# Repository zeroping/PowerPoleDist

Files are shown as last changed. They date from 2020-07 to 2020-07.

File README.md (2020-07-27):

# PowerPoleDist

An Anderson PowerPole DC power distribution box.

## What is this thing?

Amateur radio hobbyists (among others) have lots of electronic gear running off of 12 VDC, and to keep the wiring a little cleaner, many of them use PowerPole connectors from Anderson Power Products. These handy little connectors can handle up to 45 amps, and have become a defacto standard.

One of the common accessories is a power breakout, basically a “power strip” for these 12 V connections. These are available from several vendors for under $100, but I wanted some slightly different features (namely, right-angle connectors), so I designed my own.

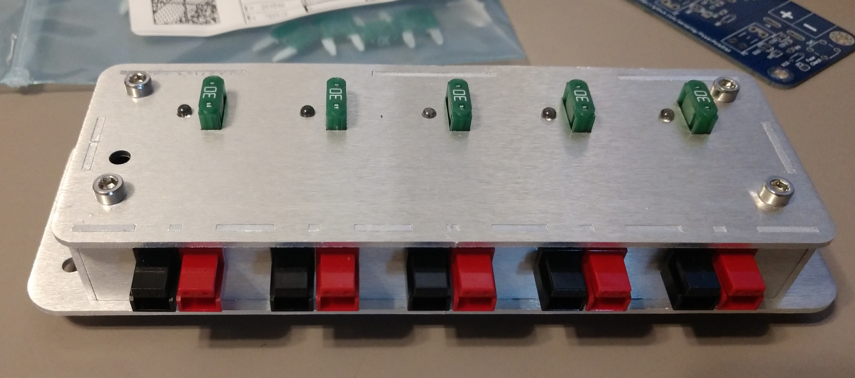
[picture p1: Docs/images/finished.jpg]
The finished design


It can handle at least 30 amps, but past that, you might want to order the PCB with 2 oz/inch copper, or solder copper wires to the PCB to lower the trace resistance.

This design is as open as I can easily make it, so if you want to change something, add something, etc, you can. The one catch is that I don't have the full 3D models for the case published (license issues), but I do have the resulting 2D shapes, so you can order your own case or make simple modifications.

The documentation should be viewable in [a pretty format on Github Pages](https://zeroping.github.io/PowerPoleDist/), or [directly in the GitHub project directory along side all the source files](https://github.com/zeroping/PowerPoleDist).

## What does it take to build one?

This design consists of:
- A custom circuit board that you can order online (design files provided)
- Electronic components that you can order from most suppliers (I used Digikey)
- A few harder-to-get components (the power connectors) available from more specialized shop (I used [Powerwerx](https://powerwerx.com/anderson-power-powerpole-sb-connectors))
- An aluminum case that you can order from a place like SendCutSend (design files provided)
- Some spacers and bolts and such that you can order from a mechanical parts supplier (I used McMaster-Carr)
 
It takes some through-hole soldering and some assembly, but the largest issue with the design is the shipping costs and one-time costs for the custom parts. The parts cost is around $30 per system, but you could easily spend three times that if you ordered just one of these, since you’re buying and shipping parts from five different vendors.

As a result, I think this design is most useful for someone building several for all their amateur radio friends, or someone who is looking for a design to modify or extend.

## Ordering Components

###  PCB files

The PCB production files are in the PCB/gerbers directory. You should be able to use the zip file as-is for most PCB manufacturers. I recommend the wonderful [PCB Shopper](https://pcbshopper.com/) to price-compare for a 2-layer, 40 x 130mm board. You might want to [check for any github issues](https://github.com/zeroping/PowerPoleDist/issues) before you order.

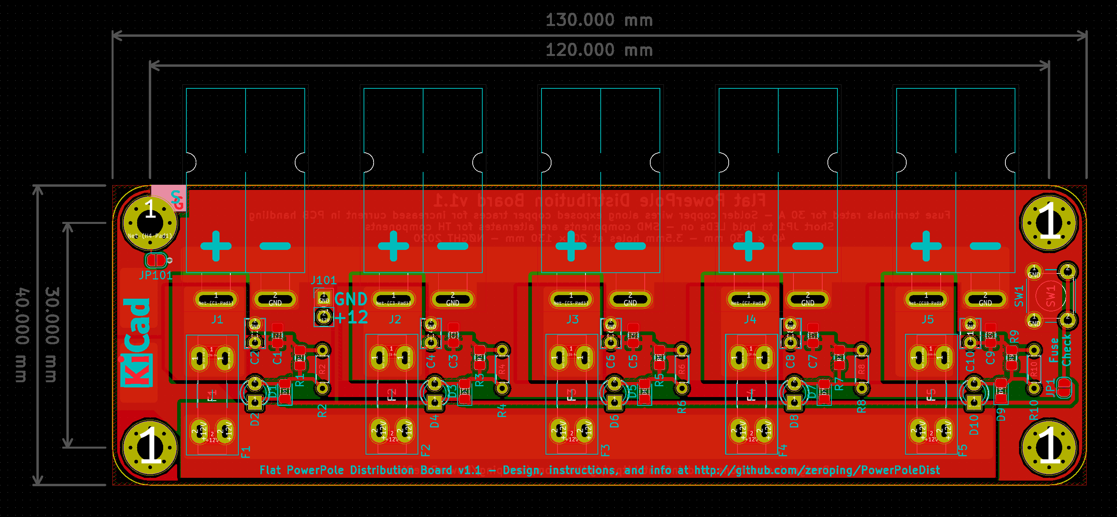
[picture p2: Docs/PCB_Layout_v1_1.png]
PCB layout
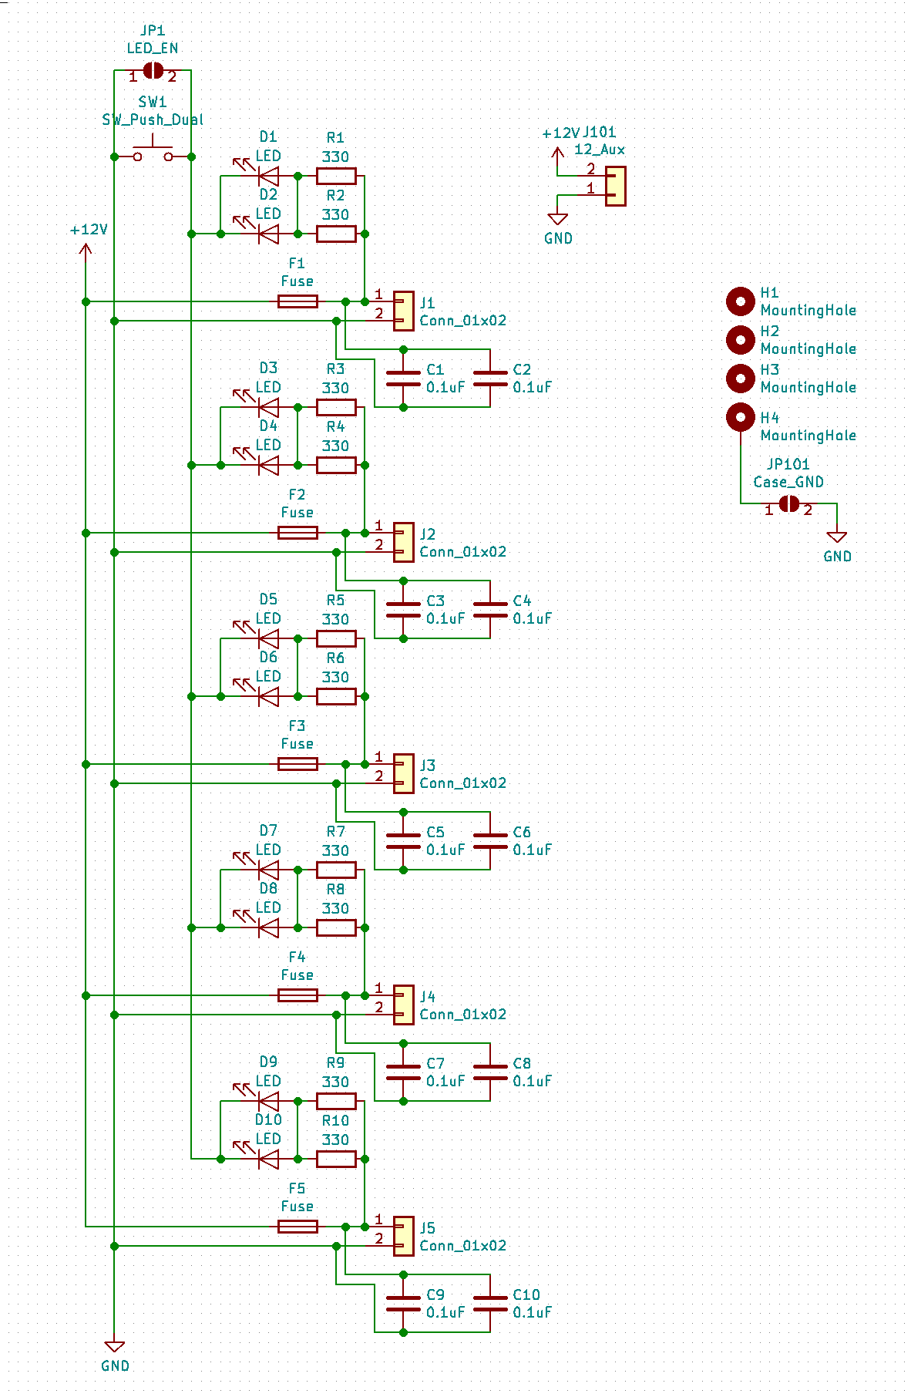
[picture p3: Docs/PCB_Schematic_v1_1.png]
schematic


The original PCB design files are in the [PCB directory](https://github.com/zeroping/PowerPoleDist/tree/master/PCB). It's designed in the open-source PCB design package [KiCad](https://kicad-pcb.org/).

### Components

A reasonable list of the parts and costs [is available here](https://github.com/zeroping/PowerPoleDist/raw/master/Docs/PowerPole_Distribution_Board_Costs.ods).

You can order all of these parts [from Digi-Key using this cart link] (https://www.digikey.com/short/zb19f1), but you may want to order the [Anderson PowerPole parts from Powerwerx](https://powerwerx.com/anderson-power-powerpole-sb-connectors) to get better prices. The links are also in [the parts list spreadsheet](https://github.com/zeroping/PowerPoleDist/raw/master/Docs/PowerPole_Distribution_Board_Costs.ods).

You'll also want to add some [Mini/APM/ATM fuses](https://www.digikey.com/product-detail/en/eaton-bussmann-electrical-division/BK-ATM-30/283-2332-ND/264848) of whatever rating you want.

They're not necessary or 100% perfect, but I've been using [these rubber feet on Amazon](https://www.amazon.com/gp/product/B07LCMS23S/ref=ppx_yo_dt_b_search_asin_title?ie=UTF8&psc=1).

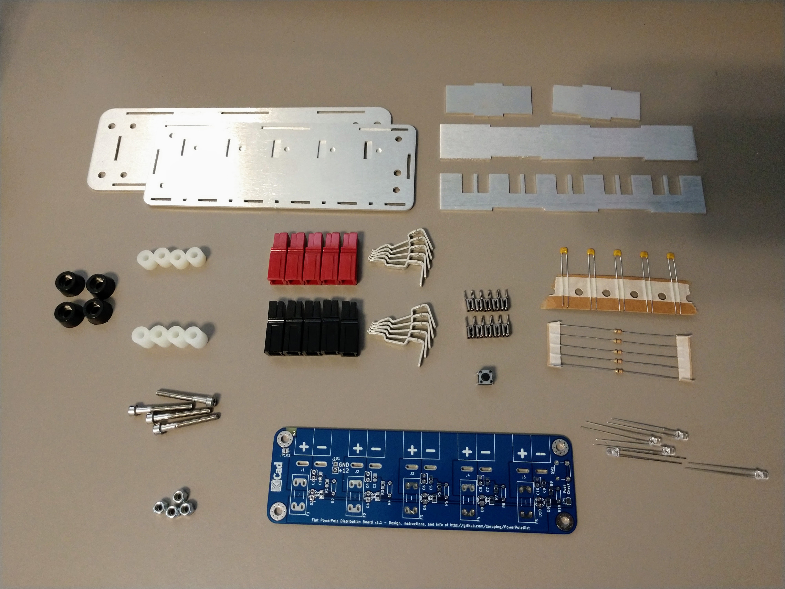
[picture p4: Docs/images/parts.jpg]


### Case

The case can be ordered by uploading the files in the [Mechanical directory](https://github.com/zeroping/PowerPoleDist/tree/master/Mechanical) to a place like [SendCutSend](https://sendcutsend.com/), in one of their 0.063” / 1.6 mm materials. I used their [5052 Aluminum](https://sendcutsend.com/aluminum/), and these are tight-fit parts, so you might want to adjust the files a tad for other materials. Be aware that they currently have a $29 minimum per material, so either order more than one, or see what else you want to get cut from metal.

There are also some M3 screws, spacers, and nuts that hold the whole thing together. I ordered these from [McMaster-Carr](https://www.mcmaster.com/), but they all come in packs of 100 – you wanted to build 25 of these, right? The links are available in [the parts list spreadsheet](https://github.com/zeroping/PowerPoleDist/raw/master/Docs/PowerPole_Distribution_Board_Costs.ods).

## Assembly

Start by putting the right-angle contacts into the Anderson PowerPole housings, and slotting the red and black housings side by side. Be sure to check which side the red goes on!

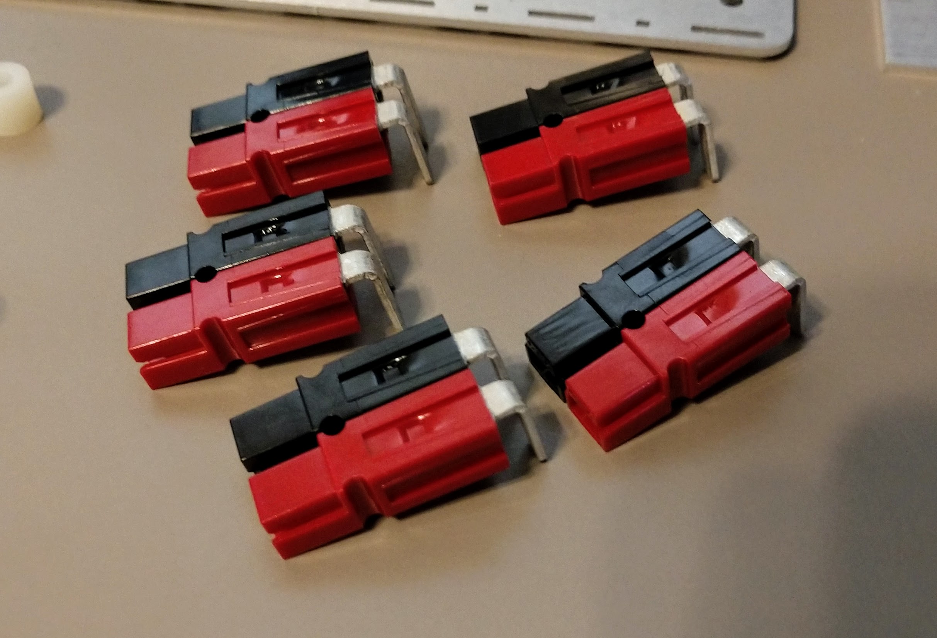
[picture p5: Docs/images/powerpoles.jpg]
Powerpoles assembled


Next, solder the high-current components into the board: the PowerPole contacts, and the fuse holders. These will all take a bit of heat from your soldering iron due to the large traces, and will take lots of solder. I haven’t managed to use too much solder yet. The fuse holders particularly don’t like to wick solder to their surfaces without enough solder on them.

I recommend using some clever supporting on a heat-resistant surface to get all of these parts held in place while you solder them. You especially want to make sure the PowerPole contacts aren’t in crooked.

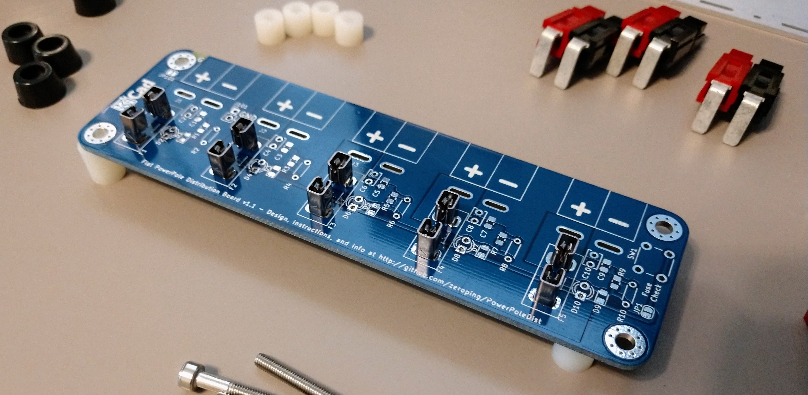
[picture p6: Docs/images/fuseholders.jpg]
Fues holder top placement


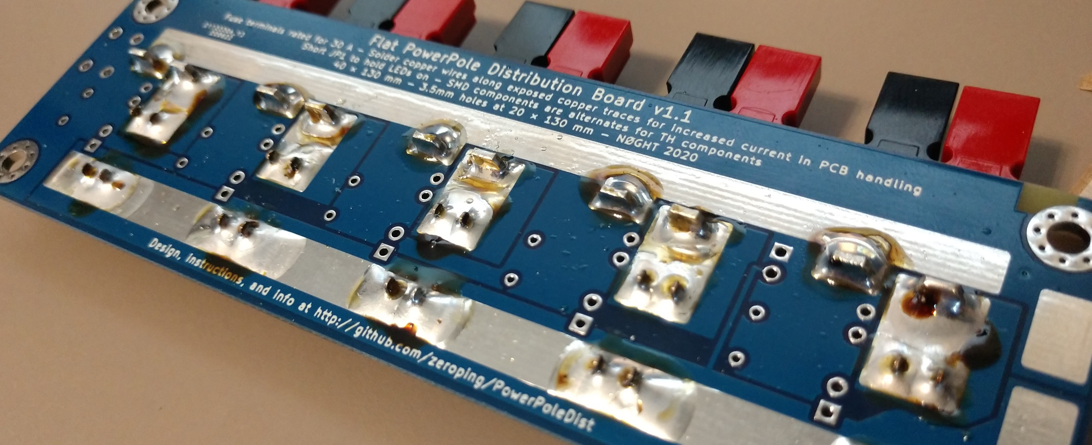
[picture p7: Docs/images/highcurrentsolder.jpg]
high current solder junctions


Then, solder all of the smaller through-hole components. This should be relatively straight forward.

The LEDs can be soldered directly on the board, or you can raise them up to get them to poke through the top of the case. If you raise them up, I recommend measuring and cutting 10 little scraps of wire insulation, and using that wire insulation to get the LEDs at the right height. Since the PCB silkscreen isn't super clear, the flat side / short leg of the LED goes away from the PowerPoles.

Decide if you want the LEDs to be on all the time, or just when you press the fuse check button. If you want them on all the time, short JP1 with some solder. Be aware, the current-limiting resistors for the LEDs were chosen to be pretty bright, so you might choose larger resistances for R1-R10 if you want them on all the time.

Also decide if you want the case connected to GND. If you do, then short jumper JP101 with some solder. I don’t recommend it, as the fuses will probably short 12V to the case if you decided to unplug one of them while the system is powered.

Next, start assembling the case. Start by threading the ‘front’ panel down between the PowerPole housings. This panel is just barely not reversible – the PowerPole housings are slight off-center and closer to the end of the board with the tactile switch. Add that to the list of fixes for the next version!

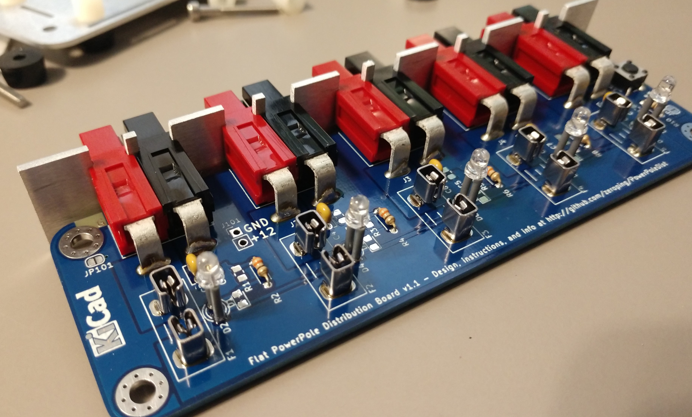
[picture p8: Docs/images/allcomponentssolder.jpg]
all of the components soldered down


Once you have the front panel in place, you can put the top on, threading the LEDs in place as as you go. You can start to fit the front panel into the top by tapping it gently with a hammer. This aluminum will bend if you’re not careful, but it makes for a satisfyingly tight fit when it goes together.

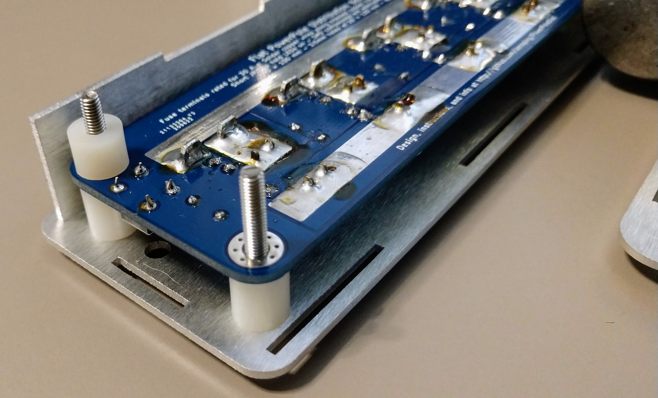
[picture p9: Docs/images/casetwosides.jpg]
case assembly


This is now your last chance to check everything over and put the spacers in before you finish assembling the case. The taller spacers go on the top of the board, and the shorter ones go below, so put those in place, and thread the long M3 screws through the case top, the spacers, and PCB. From this point on, you will want to leave the M3 screws in place to keep the spacers lined up. You might want to  put the nuts on for now to hold them in place. It is quite annoying to have to disassemble the case to re-position a spacer.

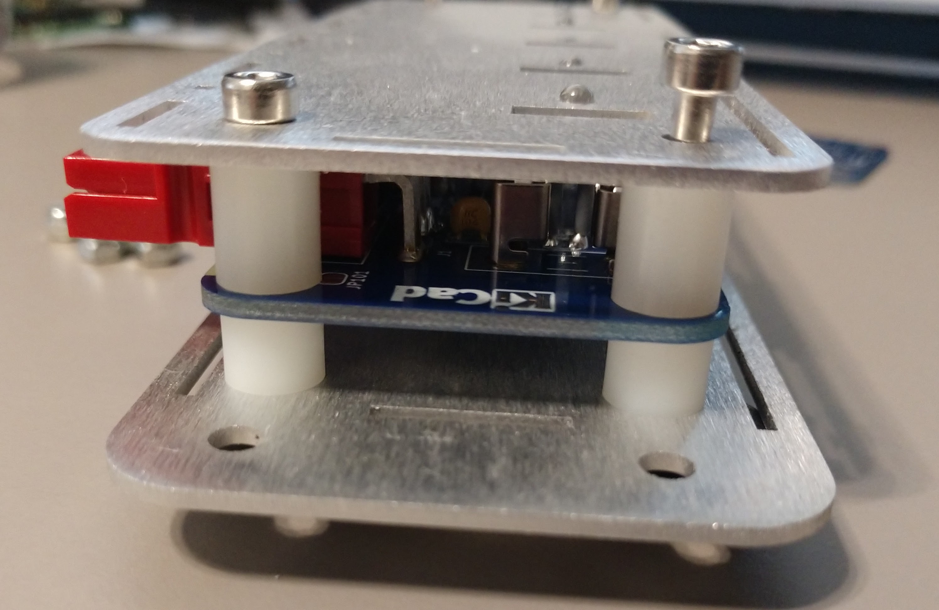
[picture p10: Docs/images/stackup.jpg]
M3 screw stackup


Now, add the case back and sides. Again, you might want to use a hammer to tap them in. Use a board edge or something to let you put the "top" against a firm, flat surface, since there are now M3 screw heads sticking out of the top.

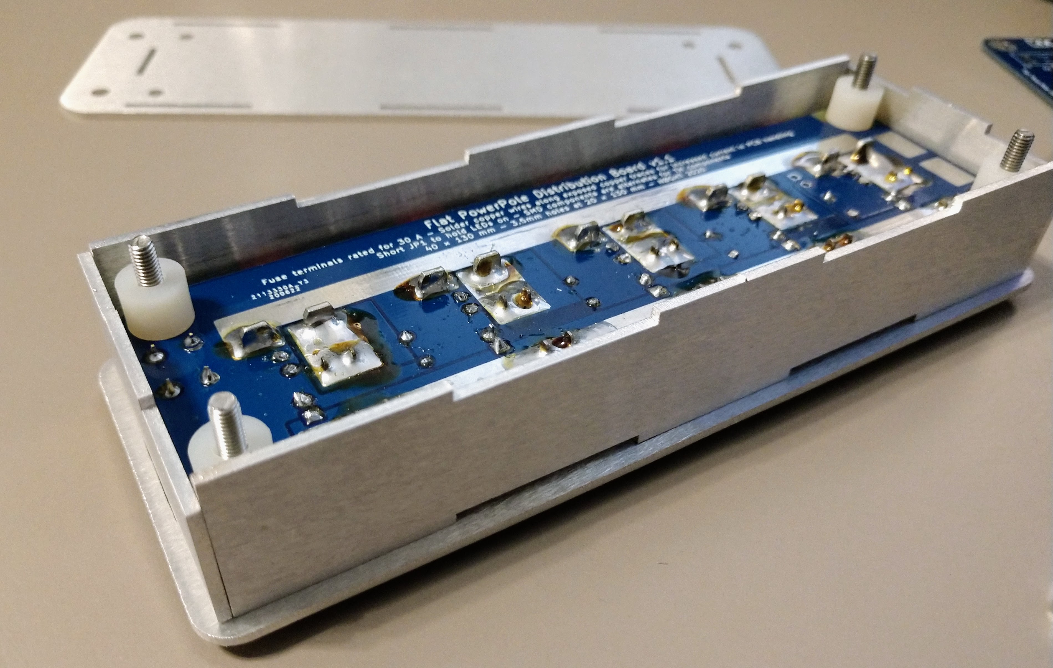
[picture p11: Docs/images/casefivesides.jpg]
case assembly


At this point, you can take the M3 nuts back off and add the case bottom. You might want to again thread the M3 nuts on to hold the screws in place while you tap the aluminum together.

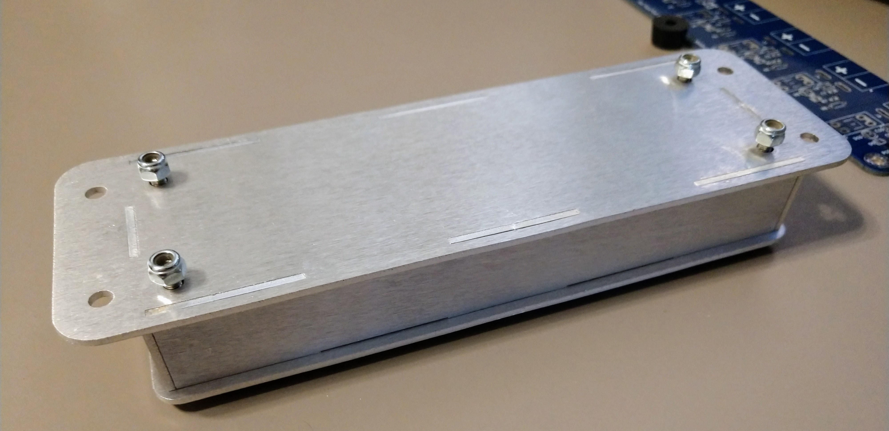
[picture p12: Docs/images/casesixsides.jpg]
case assembly


Once you get the case all slotted together, you can try adding rubber feet. The ones I found don’t fit perfectly, but they squish just enough to let these nuts thread on to the M3 screw. I have found that squishing the feet (with nuts in place) just a little bit helps me get it started, and after that, the nuts seem to lock in place enough to let you tighten them. I’d like to have better feet, but these are the best ones I’ve found that are cheap.

## Issues

Github has a way to handle [reporting issues](https://github.com/zeroping/PowerPoleDist/issues), so submit any problems there, and look there for issues that other people have hit. The nice thing about handling it here is that, even if I'm not attentive, at least the issues will all be public.

## Reuse of this design

I want this design to be open for anyone to use for hobbiest use. If you’re selling them for a profit, give me some attribution and link to this git repo. If you’re selling more than 100 for a profit, let me know - I will probably still be ok with it.

I’ll work on picking a proper license at some point, but for now, just be reasonable.

## Other references

In the very least, I wanted to point out an [alternative PowerPole distribution board by Tyler Ward, M0UAV, over on hackaday.io](https://hackaday.io/project/10489-powerpole-distribution-block). His version uses the vertical PowerPole PCB terminals, and an acrylic case, but is otherwise very similar.

I know there are a fair number of amateur radio users who are using 4-cell LiFePo4 batteries for portable DC power sources, so I'll also mention [Alex Klimaj's LiPow USB-C battery charger](https://hackaday.io/project/161771-lipow-the-usb-c-lipo-battery-charger). It doesn't support LiFePo4 chemistry right out of the box, but it's an interesting and unique design that I'm likely to use in the future for charging my home-built battery pack.

If you have a related open hardware design, let me know, and I might add a link to it here.

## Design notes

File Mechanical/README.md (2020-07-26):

These files are for the metal case. They were designed to be cut in 0.063" / 1.6 mm aluminum from [Send Cut Send ](https://sendcutsend.com/aluminum/). Note that they're a pretty tight fit as-is.

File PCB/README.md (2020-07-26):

These are the files for the circuit board, designed in KiCAD 5.0.2. There are a couple of custom libraries that I made for the Anderson PowerPole right-angle connectors and the fuse holders, but they should be included here. 

Note that there are two parallel versions of many of the fust check components - this lets you build the board using either through-hole or surface-mount components, but I recommend the through-hole components if you're building the boards as one-offs.

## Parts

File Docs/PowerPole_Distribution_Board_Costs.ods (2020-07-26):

 | Order Link | Manufacturer P/N | Description | Part Cost | Number per Unit | Cost per Unit | Bulk Price | Bulk quantity
 |  |  |  |  |  |  |  |  | My cost per unit: | $27.49
Mechanicals |  |  |  |  |  | $1.30 |  |  | My cost per unit (including 1/5 of extra costs): | $42.94
 | 94639A332 (https://www.mcmaster.com/catalog/94639A332) |  | Nylon Unthreaded Spacer 5/16" OD, 1/4" Long | $0.10 | 4 | $0.39 | $9.72 | 100 | My cost for parts to put two connectors on wire: | $1.06
 | 94639A334 (https://www.mcmaster.com/catalog/94639A334) |  | Nylon Unthreaded Spacer 5/16" OD, 3/8" Long | $0.10 | 4 | $0.41 | $10.22 | 100 | My costs for a 5-foot pigtail (one connector) | $5.87
 | 93625A100 (https://www.mcmaster.com/catalog/93625A100) |  | Stainless Steel Locknut, M3 x 0.5 mm Thread | $0.05 | 4 | $0.21 | $5.31 | 100 | My costs for a 5-foot cable (two connectors) | $11.74
 | 91292A020 (https://www.mcmaster.com/catalog/91292A020) |  | Stainless Steel Screw, M3 x 0.5 mm Thread, 25 mm Long | $0.07 | 4 | $0.29 | $7.23 | 100 | Amount I've spent on project | $446.83
 | https://www.amazon.com/gp/product/B07LCMS23S/ref=ppx_yo_dt_b_search_asin_title?ie=UTF8&psc=1 |  | uxcell Rubber Feet Bumpers Pads D12x10xH7mm Black | $0.17 | 4 | $0.67 | $8.38 | 50
Case Parts |  |  | 0.062" / 1.6mm 5052 Aluminum |  |  | $15.64
 |  | Custom | Top | $5.41 | 1 | $5.41 | $27.05 | 5
 |  | Custom | Bottom | $4.27 | 1 | $4.27 | $21.35 | 5
 |  | Custom | Short sides | $1.07 | 2 | $2.14 | $10.70 | 10
 |  | Custom | Long side | $1.45 | 1 | $1.45 | $7.25 | 5
 |  | Custom | Long side, Power Pole | $2.37 | 1 | $2.37 | $11.85 | 5
Powerpole Parts |  |  |  |  |  | $7.80
 | 1327-BK (https://powerwerx.com/1327bk-anderson-powerpole-housing-red) |  | Anderson PP15/30/45 Powerpole Housing, Red | $0.35 | 5 | $1.75 | $17.50 | 50
 | 1327G6-BK (https://powerwerx.com/1327g6bk-anderson-powerpole-housing-black) |  | Anderson PP15/30/45 Powerpole Housing, Black | $0.35 | 5 | $1.75 | $17.50 | 50
 | 1336G1 (https://powerwerx.com/anderson-1336g1-printed-circuit-board-horizontal) |  | Anderson PCB 45 Amp Horizontal Bottom Contact | $0.43 | 10 | $4.30 | $43.00 | 100
Electronic Parts |  |  |  |  |  | $2.75
 | 36-3557-ND (https://www.digikey.com/product-detail/en/keystone-electronics/3557/36-3557-ND/2092485) | Keystone 3557 | Fuse Clip 500V 30A | $0.15 | 10 | $1.45 | $14.51 | 100
 | S330QCT-ND (https://www.digikey.com/product-detail/en/stackpole-electronics-inc/CFM14JT330R/S330QCT-ND/2617736) | Stackpole CFM14JT330R | Resistor, 330 ohm 5% 1/4 w | $0.02 | 5 | $0.08 | $1.69 | 100
 | 1830-1000-ND (https://www.digikey.com/product-detail/en/inolux/INL-3AR30/1830-1000-ND/7604620) | Inolux INL-3AR30 | LED, 3 mm Red | $0.13 | 5 | $0.64 | $12.73 | 100
 | BC1148CT-ND (https://www.digikey.com/product-detail/en/vishay-bc-components/K104Z15Y5VE5TL2/BC1148CT-ND/286770) | Vishay K104Z15Y5VE5TL2 | 25V 0.1 uF Capacitor | $0.10 | 5 | $0.49 | $9.78 | 100
 | 679-2428-ND (https://www.digikey.com/product-detail/en/apem-inc/MJTP1230/679-2428-ND/1798037) | APEM MJTP1230 | Tactile Switch, 6x6mm | $0.09 | 1 | $0.09 | $1.74 | 20
 |  | Custom | PCB | $0.70 | 1 | $0.70 | $7.00 | 10
Other Costs Incurred |  |  |  |  |  | $15.45 | $77.24
 |  |  | PCB shipping |  |  |  | $17.44
 |  |  | v1.0 PCB order |  |  |  | $22.81
 |  |  | McMaser-Carr Shipping |  |  |  | $6.63
 |  |  | Digikey Shipping |  |  |  | $4.99
 |  |  | PowerWX shipping |  |  |  | $14.46
 |  |  | SendCutSend discount (!) |  |  |  | -$7.82
 |  |  | Crimp Tool Die Set for Power Pole 15 30 45 Connections - by W5SWL |  |  |  | $18.73
Bonus Parts
 | RT-1 (https://powerwerx.com/powerpole-insertion-removal-extraction-tool) |  | Powerwerx Powerpole Insertion, Removal & Extraction Tool | $9.99 |  |  | $9.99 | 1
 | 1332-BK (https://powerwerx.com/anderson-1332-powerpole-contact-pp15) |  | Anderson PP15 Powerpole Contact, 16-20 GA, 15A | $0.18 |  |  | $4.50 | 25
 | 1331-BK (https://powerwerx.com/anderson-1331-powerpole-contact-pp30) |  | Anderson PP30 Powerpole Contact, 12-14 GA, 30A | $0.18 |  |  | $4.50 | 25
 | 1335G1 (https://powerwerx.com/anderson-1335g1-printed-circuit-board-vertical) |  | Anderson Power 1335G1 Printed Circuit Board High Power 45 Amp Vertical Contact | $0.59 |  |  | $1.18 | 2
 | 1337G1 (https://powerwerx.com/anderson-1337g1-printed-circuit-board-horizontal) |  | Anderson Power 1337G1 Printed Circuit Board High Power 45 Amp Horizontal Top Contact | $0.56 |  |  | $1.12 | 2
 | ROLL-30-25 (https://powerwerx.com/roll-pins-15-30-45-amp-powerpole-housings) |  | Roll Pins for 15, 30 & 45 Amp Powerpole Housings | $0.10 |  |  | $2.50 | 25
 | Wire-RB-12-25 (https://powerwerx.com/redblack-zip-cord-12-25) |  | Red/Black Zip Cord (Gauge: 12, Length: 25 ft.) | $0.96 |  |  | $24.05 | 25

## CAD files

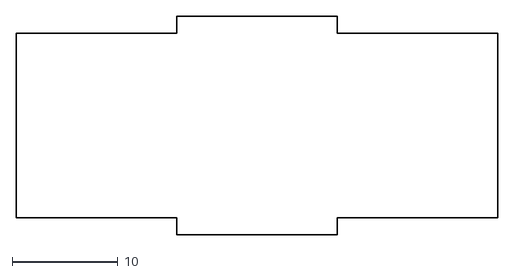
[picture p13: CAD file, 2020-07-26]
Mechanical/ppbside.dxf
45.5 x 20.7

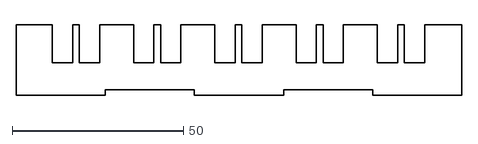
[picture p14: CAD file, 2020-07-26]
Mechanical/ppbfront.dxf
130.0 x 20.7

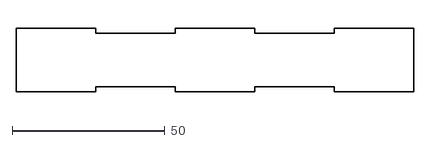
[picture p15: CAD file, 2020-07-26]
Mechanical/ppbback.dxf
130.0 x 20.7

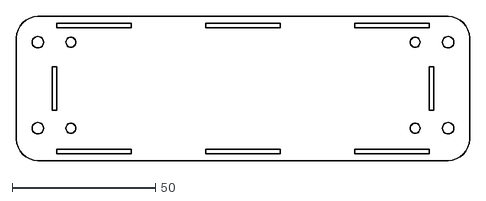
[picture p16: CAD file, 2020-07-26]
Mechanical/ppbbottom.dxf
158.0 x 50.3

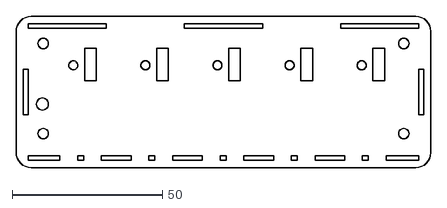
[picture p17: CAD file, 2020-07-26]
Mechanical/ppbtop.dxf
138.0 x 50.3

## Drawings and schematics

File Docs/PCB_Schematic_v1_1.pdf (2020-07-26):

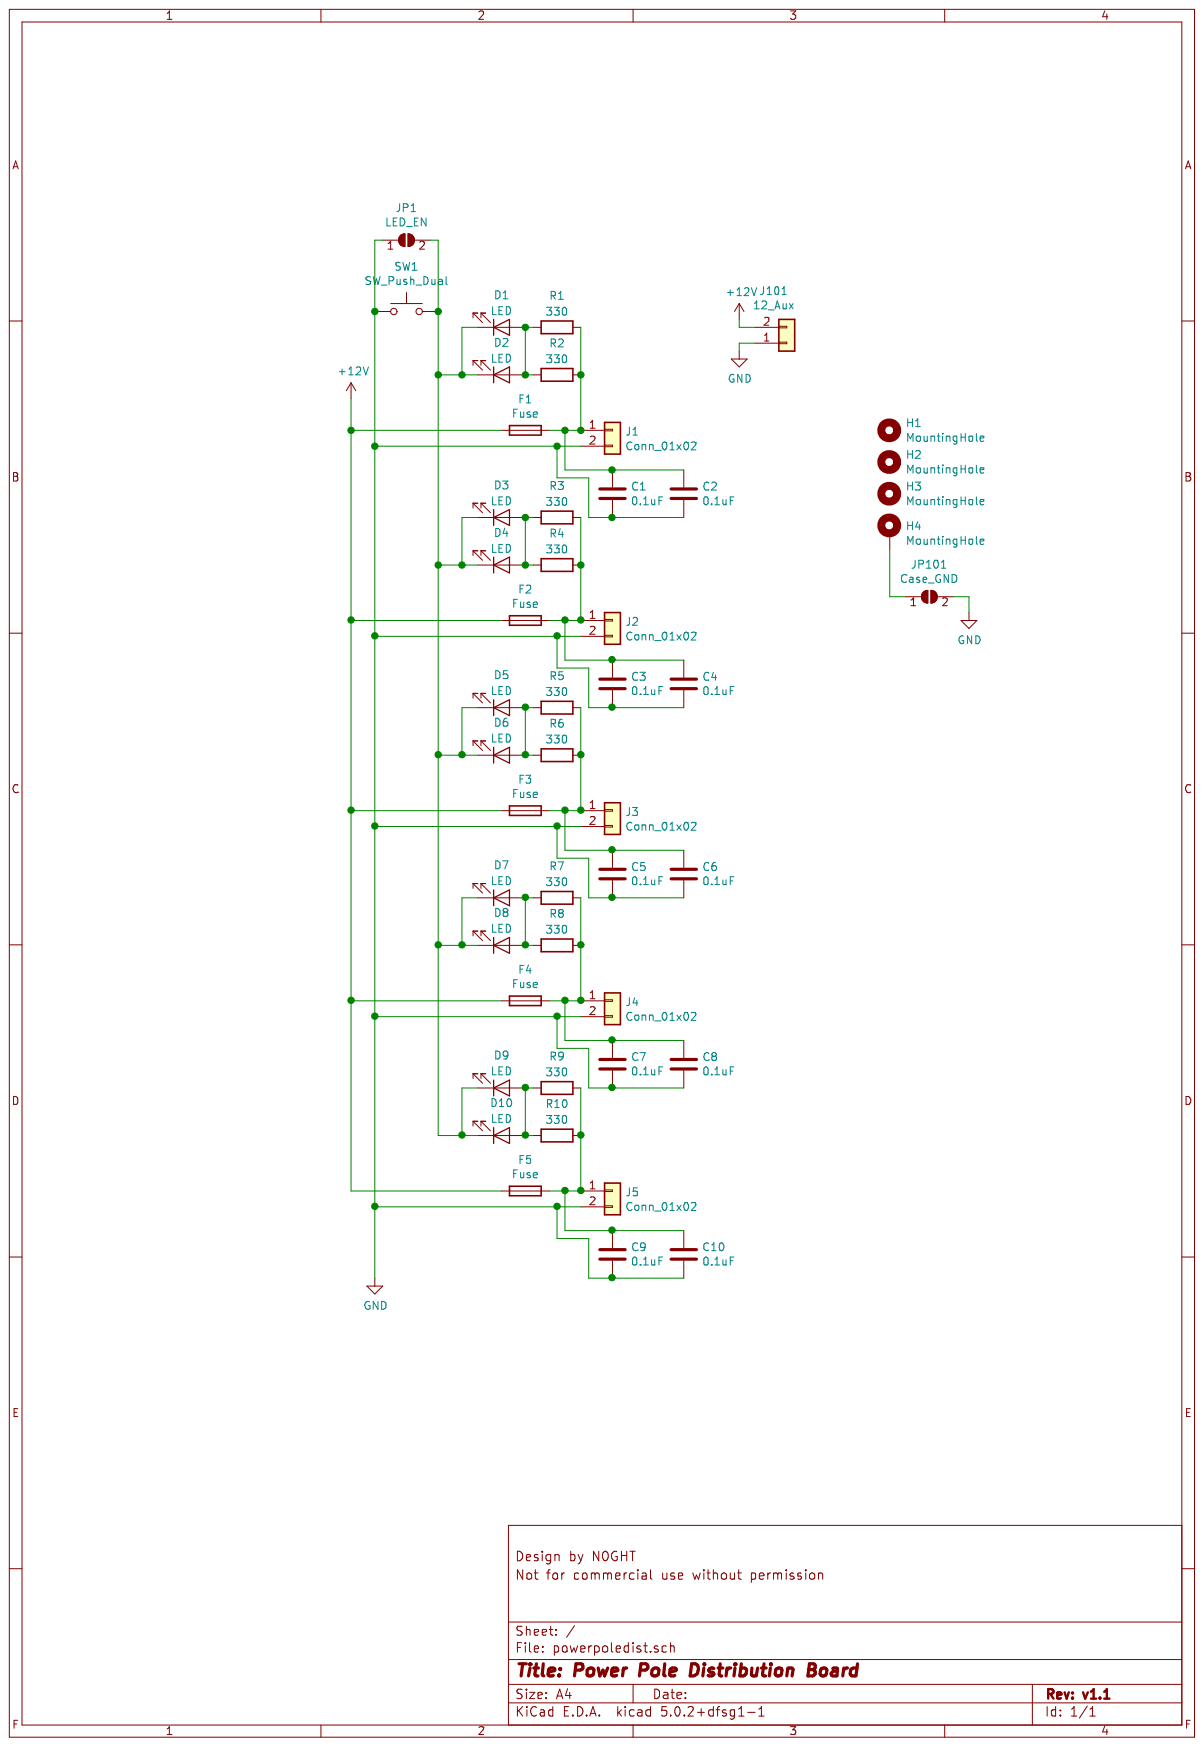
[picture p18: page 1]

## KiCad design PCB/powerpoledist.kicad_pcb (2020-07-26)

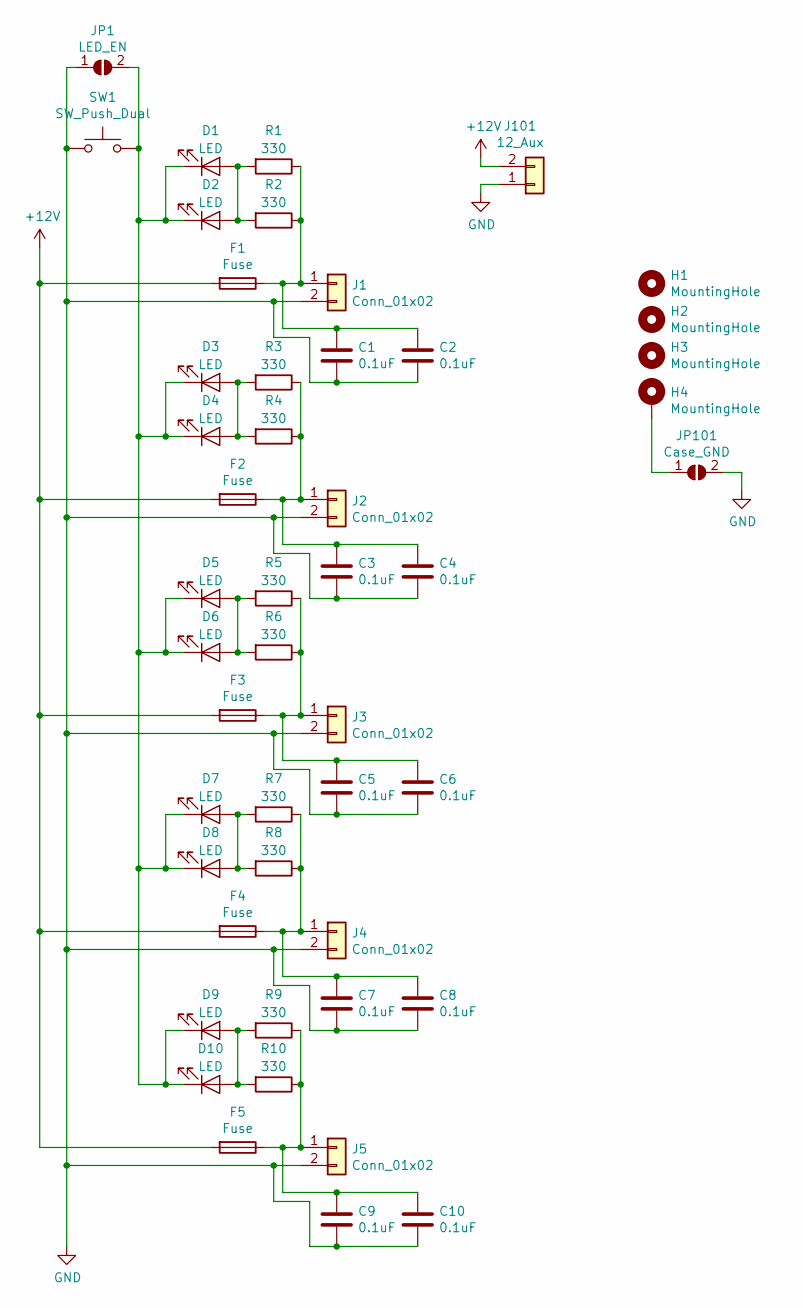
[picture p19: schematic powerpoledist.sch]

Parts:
C1, C3, C5, C7, C9: 0.1uF; C_0805_2012Metric_Pad1.15x1.40mm_HandSolder; MPN C0805C104M3RACTU
C2, C4, C6, C8, C10: 0.1uF; C_Disc_D3.8mm_W2.6mm_P2.50mm; MPN K104Z15Y5VE5TL2
D1, D3, D5, D7, D9: LED; D_0805_2012Metric_Pad1.15x1.40mm_HandSolder; MPN LTST-S220GKT
D2, D4, D6, D8, D10: LED; LED_D3.0mm; MPN INL-3AR30
F1, F2, F3, F4, F5: Fuse; Fuseholder_Blade_Mini_Keystone_3557_Slots; MPN 3557
H1, H2, H3, H4: MountingHole; MountingHole_3.5mm_Pad_Via
J1, J2, J3, J4, J5: Conn_01x02; PowerPole_PP45_1336G1_1x2_Horizontal; MPN 1336G1
J101: 12_Aux; PinHeader_1x02_P2.54mm_Vertical
JP1: LED_EN; SolderJumper-2_P1.3mm_Open_RoundedPad1.0x1.5mm
JP101: Case_GND; SolderJumper-2_P1.3mm_Open_RoundedPad1.0x1.5mm
R1, R3, R5, R7, R9: 330; R_0805_2012Metric_Pad1.15x1.40mm_HandSolder; MPN RMCF0805JT330R
R2, R4, R6, R8, R10: 330; R_Axial_DIN0204_L3.6mm_D1.6mm_P5.08mm_Horizontal; MPN ‎CFM14JT330R‎
SW1: SW_Push_Dual; SW_PUSH_6mm_H4.3mm; MPN MJTP1230

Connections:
+12V: F1.2, F2.2, F3.2, F4.2, F5.2, J101.2
GND: C1.2, C2.2, C3.2, C4.2, C5.2, C6.2, C7.2, C8.2, C9.2, C10.2, J1.2, J2.2, J3.2, J4.2, J5.2, J101.1, JP1.1 (A), JP101.2 (B), SW1.1
unnamed: C1.1, C2.1, F1.1, J1.1, R1.1, R2.1
unnamed: C3.1, C4.1, F2.1, J2.1, R3.1, R4.1
unnamed: C5.1, C6.1, F3.1, J3.1, R5.1, R6.1
unnamed: C7.1, C8.1, F4.1, J4.1, R7.1, R8.1
unnamed: C9.1, C10.1, F5.1, J5.1, R9.1, R10.1
unnamed: D1.1 (K), D2.1 (K), D3.1 (K), D4.1 (K), D5.1 (K), D6.1 (K), D7.1 (K), D8.1 (K), D9.1 (K), D10.1 (K), JP1.2 (B), SW1.2
unnamed: D1.2 (A), D2.2 (A), R1.2, R2.2
unnamed: D3.2 (A), D4.2 (A), R3.2, R4.2
unnamed: D5.2 (A), D6.2 (A), R5.2, R6.2
unnamed: D7.2 (A), D8.2 (A), R7.2, R8.2
unnamed: D9.2 (A), D10.2 (A), R9.2, R10.2
unnamed: H4.1, JP101.1 (A)

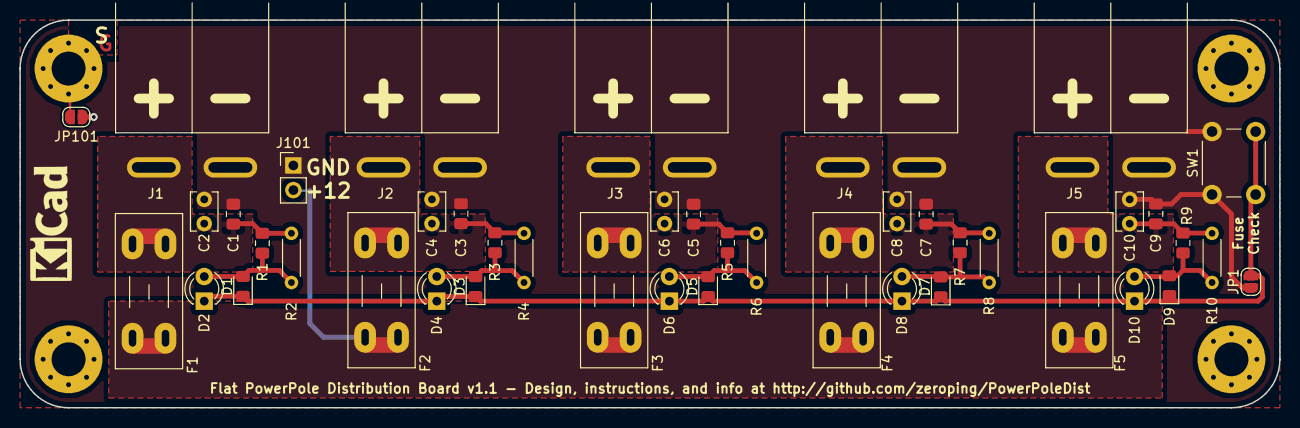
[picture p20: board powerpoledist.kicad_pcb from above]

Board: 2 copper layers, 130.0 x 40.0 mm, 48 parts (0 on the bottom side), 14 nets.

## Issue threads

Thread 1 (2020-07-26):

Front panel is almost reversible/confusing

zeroping, 2020-07-26:
The front panel design is nearly symmetric, which means it looks like it can go either direction, but can't really. The powerpoles are slightly closer to the end with the fuse test switch.

To fix this, I should probably change the case and front so that they only slot together one way.

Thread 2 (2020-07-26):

v1.1 PCB's have some through-hole pins thermally connected to the GND plane

zeroping, 2020-07-26:
The GND pin on each LED, as well as two GND pins on SW1 are completely connected to the GND plane. This makes them harder to solder (the GND plane soaks up heat, making these pads hard to heat up.)

The right fix is to mark these pads as "Pad connection: Thermal relief", while leaving the high-current connections (the PowerPoles) set to "Pad connection: Solid". It's a simple fix, but is wrong in the gerbers, zip file, and all v1.1 boards already produced.

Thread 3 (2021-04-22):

The Middle Part is Broken

JeffHochberg, 2021-04-22:
OK - I understand the parts (mostly) and I understand what the finished product is supposed to look like.

It's all the stuff in between that seems completely and totally flawed. You mean I am meant to put all this stuff together?

I paid good money for these components! And now I'm expected to screw and solder everything together? That's not fair! :-)

I give this project an F minus in terms of effort and execution. I'd strongly advise starting from scratch and rethinking your strategy.

;-)

Just kidding! Great work. Would you believe I'm just getting around to starting this project? I'm excited about being able to do something like this myself. It should be really good soldering practice.

One question - as far as the tabs and slots, are they truly meant to fit together? To say the fit is snug is an understatement. I practically sliced my fingers off trying to get the tabs pushed into the slots. I will probably need to use a very high gauge Dremel bit to grind out some of the material to get them together - unless you have a better recommendation.

Don't you miss my crass sense of humor? Someone needed to use the Issues section of this repo. LOL

It would be nice to hear from you soon. I hope I don't need to resort to these antics to get your attention. :-)

-JeffH

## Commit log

2020-07-26 Initial commit of PCB files as used for board v1.1
    [powerpoledist.kicad_pcb, powerpoledist.sch]
2020-07-26 Gerber files used to produce board v1.1
    [powerpoledist-B.Cu.gbr, powerpoledist-B.Mask.gbr, powerpoledist-B.SilkS.gbr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]
2020-07-26 Added mechanical files
    [ppbback.dxf, ppbbottom.dxf, ppbfront.dxf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]
2020-07-26 More readme edits and embedded images
    [PowerPole_Distribution_Board_Costs.ods]
